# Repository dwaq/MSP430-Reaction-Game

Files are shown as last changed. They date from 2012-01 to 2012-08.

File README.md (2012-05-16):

MSP430-Reaction-Game
====================

The object of the game is to stop the cycling LEDs at a specific LED to test your reaction skills. The TI MSP430G2231 microcontroller drives 8 LEDs via 3 pins using a 74HC595 shift register. The speed that the LEDs flash is determined from the potentiometer wiper via the analog to digital converter in the MSP430. There are also 2 pushbuttons to start/restart and stop the game. Everything is powered from a 9V battery that is dropped down to 3.3V via a LD1117V33 voltage regulator. There is also a programming header to program the microcontroller in-circuit with a TI Launchpad.

Read the full details on my blog at http://tinkeringetc.blogspot.com/p/msp430-reaction-game.html

This work is licensed under a Creative Commons Attribution 3.0 Unported License.

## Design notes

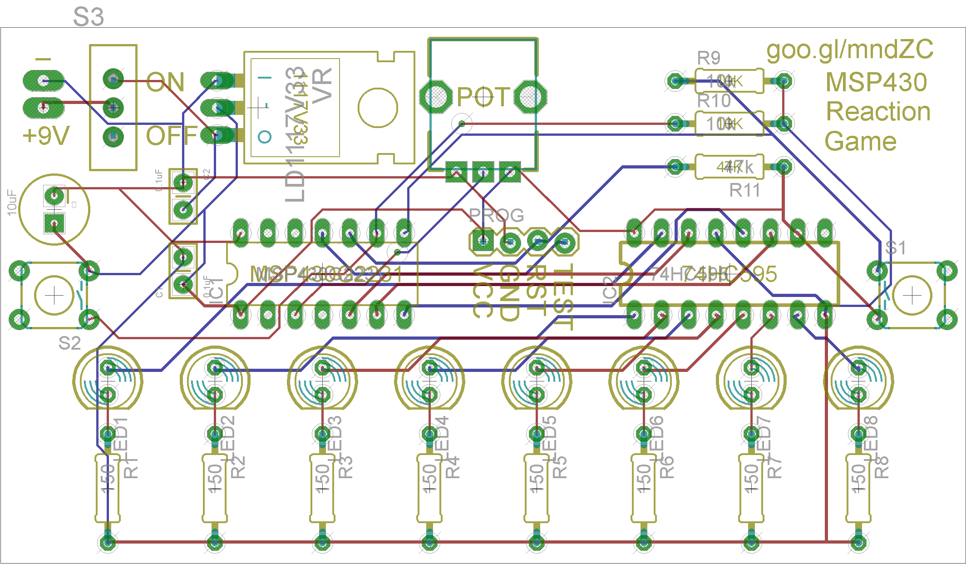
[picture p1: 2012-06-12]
ReactionGame.brd.png

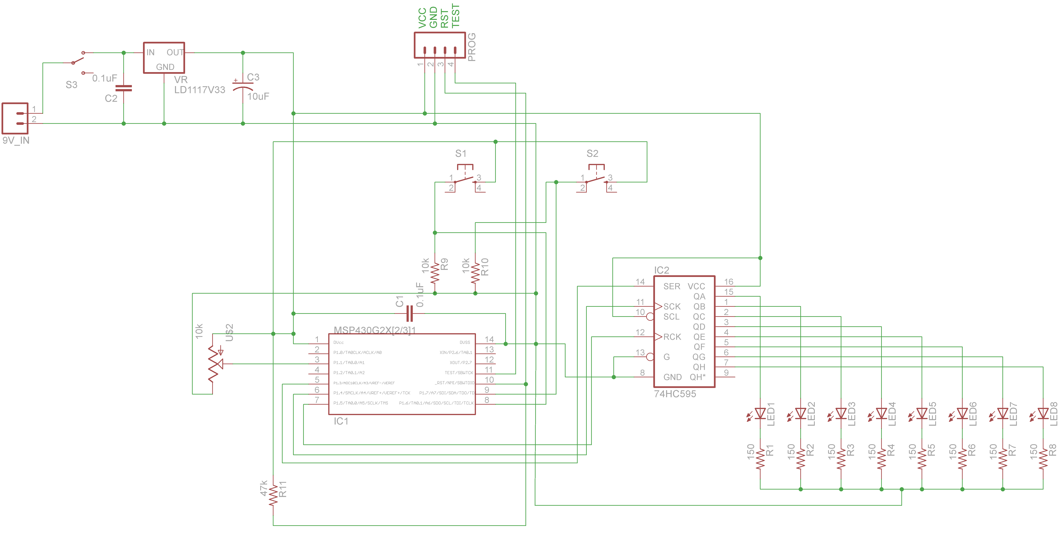
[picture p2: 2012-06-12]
ReactionGame.sch.png

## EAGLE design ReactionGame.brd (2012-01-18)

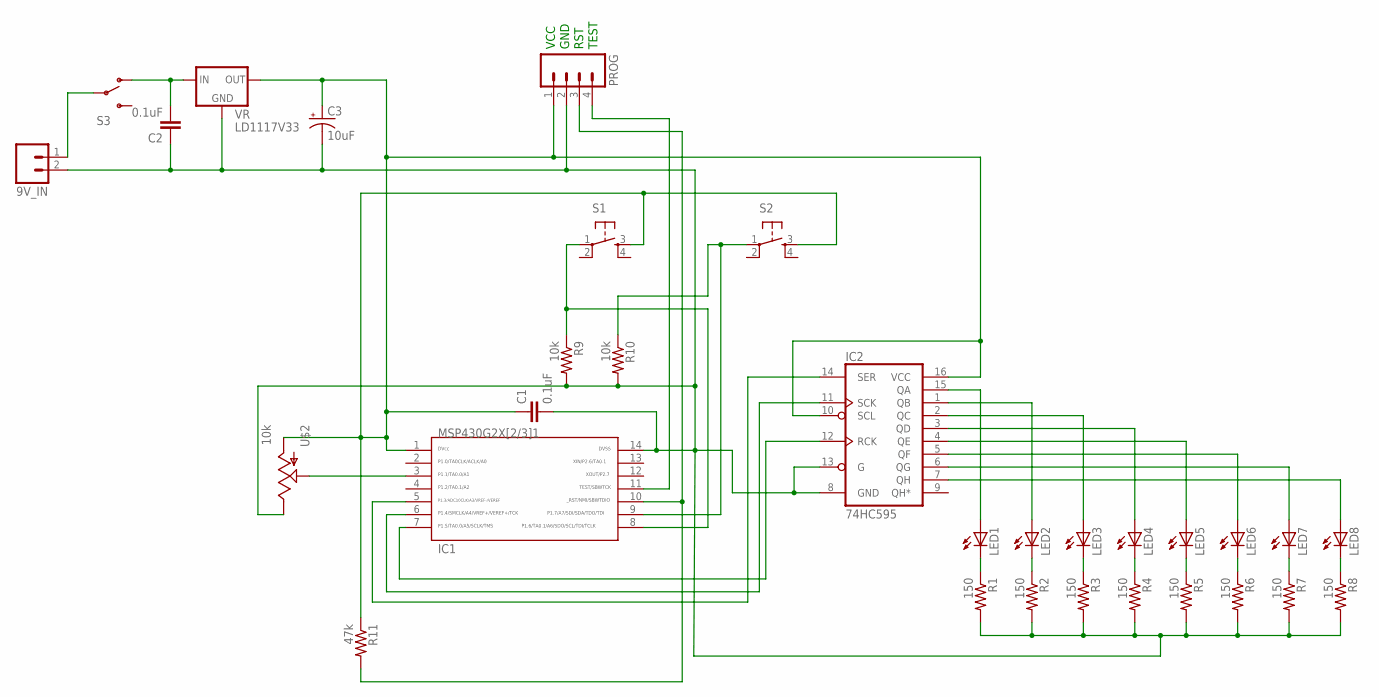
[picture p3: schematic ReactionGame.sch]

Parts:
9V_IN: M02PTH3; 1X02_LONGPADS
C1, C2: 0.1uF; CAP-PTH-SMALL2
C3: 10uF; CPOL-RADIAL-100UF-25V
IC1: MSP430G2231; N14
IC2: 74HC595; DIL16
LED1, LED2, LED3, LED4, LED5, LED6, LED7, LED8: LED5MM
PROG: M04LOCK; 1X04_LOCK
R1, R2, R3, R4, R5, R6, R7, R8: 150; 0207/10
R9, R10: 10k; 0207/10
R11: 47k; 0207/10
S1, S2: TAC_SWITCHPTH; TACTILE-PTH
S3: SWITCH-SPSTKIT; SWITCH-SPDT_KIT
U$2: 10k; ALPS_POT
VR: LD1117V33; 78XXL

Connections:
unnamed: LED1.K (C), R1.1
unnamed: LED2.K (C), R2.1
unnamed: LED3.K (C), R3.1
unnamed: LED4.K (C), R4.1
unnamed: LED5.K (C), R5.1
unnamed: LED6.K (C), R6.1
unnamed: LED7.K (C), R7.1
unnamed: LED8.K (C), R8.1
unnamed: IC2.15 (QA), LED1.A
unnamed: IC2.1 (QB), LED2.A
unnamed: IC2.2 (QC), LED3.A
unnamed: IC2.3 (QD), LED4.A
unnamed: IC2.4 (QE), LED5.A
unnamed: IC2.5 (QF), LED6.A
unnamed: IC2.6 (QG), LED7.A
unnamed: IC2.7 (QH), LED8.A
unnamed: IC1.3, U$2.P$2 (S)
unnamed: IC1.10, PROG.3, R11.2
unnamed: IC1.5, IC2.14 (SER)
unnamed: IC1.7, IC2.12 (RCK)
unnamed: IC1.6, IC2.11 (SCK)
unnamed: IC1.8, R9.1, S1.1
unnamed: IC1.9, R10.1, S2.1
unnamed: 9V_IN.2, C1.2, C2.1, C3.2 (-), IC1.14, IC2.8 (GND), IC2.13 (G), PROG.2, R1.2, R2.2, R3.2, R4.2, R5.2, R6.2, R7.2, R8.2, R9.2, R10.2, U$2.P$1 (E), VR.IN (GND)
unnamed: IC1.11, PROG.4
unnamed: 9V_IN.1, S3.2
unnamed: C2.2, S3.1 (O), VR.OUT (IN)
unnamed: C1.1, C3.1 (+), IC1.1, IC2.10 (SCL), IC2.16 (VCC), PROG.1, R11.1, S1.3, S2.3, U$2.P$3 (A), VR.GND (OUT)

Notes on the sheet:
VCC
GND
RST
TEST

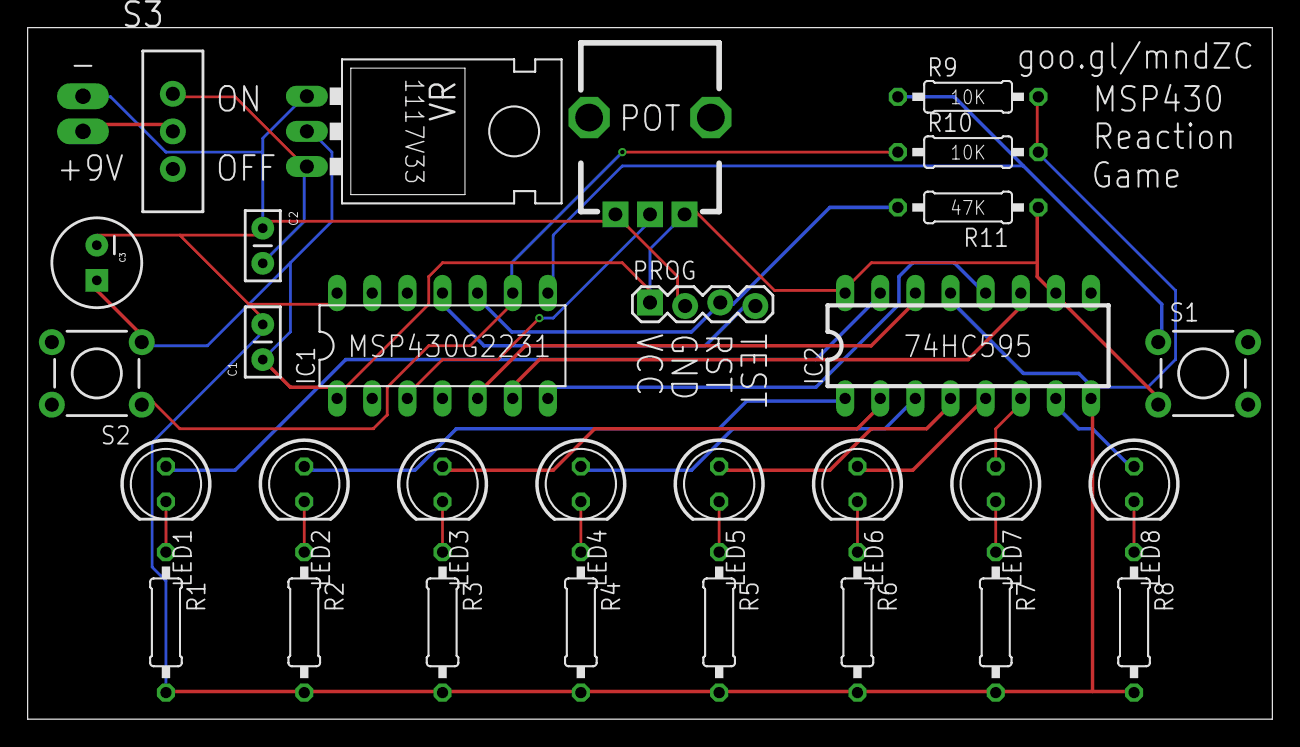
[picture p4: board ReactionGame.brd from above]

Board: 2 copper layers, 90.0 x 50.0 mm, 31 parts (0 on the bottom side), 28 nets.

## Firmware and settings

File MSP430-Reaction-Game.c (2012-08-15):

//*************************************************************************************************
// MSP430 Reaction Game
//
// By: Dillon Nichols
// http://tinkeringetc.blogspot.com/p/msp430-reaction-game.html
//
// Created in Code Composer Studio v4.2.5
//
// Description: 
// Drives 8 LEDs using a shift register at a user selected rate 
// The object of the game is to stop the LEDs at a specific LED
//
// Special thanks to:
// * TI's example code for the ADC10 located at http://www.ti.com/litv/zip/slac463a
// * Andrew Morton's example of interfacing the 74HC595 shift register to the MSP430 located at
//   http://processors.wiki.ti.com/index.php/MSP430_Launchpad_Shift_Register
// * Christopher Chenoweth's delay function located at: http://www.threadabort.com/?p=26
// * The "SCIENTIFIC INSTRUMENTS USING THE TI MSP430" blog located at http://mspsci.blogspot.com/
//
// This work is licensed under a Creative Commons Attribution 3.0 Unported License.
//*************************************************************************************************
#include "msp430g2231.h"
 
// Define pins
#define POT   BIT1 	// POTENTIOMETER -> P1.1
#define DATA  BIT3 	// PIN 14 OF 74HC595 -> P1.3
#define CLOCK BIT4 	// PIN 11 OF 74HC595 -> P1.4
#define LATCH BIT5 	// PIN 12 OF 74HC595 -> P1.5
#define STOP  BIT6 	// GAME STOP / RESTART BUTTON -> P1.6
#define START BIT7	// LED START / RESET BUTTON -> P1.7

// Declare functions
void game (void);
void stop (void);
void restart (void);
void delay (unsigned int);
void pinWrite (unsigned int, unsigned char);
void pulseClock (void);
void shiftOut (unsigned char);

// Store time between LED flashes as a global variable so all functions can access it
int delayTime;		

// Uses potentiometer through the ADC10 to select how quickly LEDs will cycle
int main(void) {
	WDTCTL = WDTPW + WDTHOLD;					// Stop WDT
	ADC10CTL0 = ADC10SHT_2 + ADC10ON + ADC10IE;	// ADC10ON, interrupt enabled
	ADC10CTL1 = INCH_1;							// input A1
	ADC10AE0 |= 0x02;							// P1.1 ADC input select
	P1DIR |= (DATA + CLOCK + LATCH);			// Setup shift register pins as outputs

  	// Reads ADC values and lights LEDS and sets the delay time corresponding to the input voltage
  	// Lower values on the ADC equals more delayTime
	for (;;) {
		ADC10CTL0 |= ENC + ADC10SC;             // Sampling and conversion start
  		__bis_SR_register(CPUOFF + GIE);        // LPM0, ADC10_ISR will force exit
		
		if (ADC10MEM > 0x000) {
  			shiftOut(1 << 7);
  			delayTime = 100;  }
	  	if (ADC10MEM > 0x07F) {
  			shiftOut(1 << 6);
  			delayTime = 90;   }
	  	if (ADC10MEM > 0x0FF) {
		  	shiftOut(1 << 5);
		  	delayTime = 80;   }
	  	if (ADC10MEM > 0x17F) {
		  	shiftOut(1 << 4);
		  	delayTime = 70;   }
	  	if (ADC10MEM > 0x1FF) {
		  	shiftOut(1 << 3);
		  	delayTime = 60;   }
	  	if (ADC10MEM > 0x27F) {
		  	shiftOut(1 << 2);
		  	delayTime = 50;   }
		if (ADC10MEM > 0x2FF) {
		  	shiftOut(1 << 1);
		  	delayTime = 40;   }
		if (ADC10MEM > 0x37F) {
	    	shiftOut(1 << 0);
	    	delayTime = 30;   }
	  	if ((P1IN & START) == START) {	// When the START button is pressed, the game
	  		game();         }			// will start with the selected delayTime	
	}
}

// ADC10 interrupt service routine
#pragma vector=ADC10_VECTOR
__interrupt void ADC10_ISR(void)
{
  __bic_SR_register_on_exit(CPUOFF);	// Clear CPUOFF bit from 0(SR)
}

// Function that flashes the LEDs back and forth with a delay between LEDs of delayTime
// Waits for the STOP button to be pressed to stop the LED and win/(lose?) the game
void game(void){
	for (;;){
    	shiftOut(1 << 0);
      	delay(delayTime); 
      	if ((P1IN & STOP) == STOP) {stop();}
    	shiftOut(1 << 1);
      	delay(delayTime); 
      	if ((P1IN & STOP) == STOP) {stop();}
      	shiftOut(1 << 2);
      	delay(delayTime); 
      	if ((P1IN & STOP) == STOP) {stop();}
      	shiftOut(1 << 3);
      	delay(delayTime); 
      	if ((P1IN & STOP) == STOP) {stop();}
      	shiftOut(1 << 4);
      	delay(delayTime); 
      	if ((P1IN & STOP) == STOP) {stop();}
      	shiftOut(1 << 5);
      	delay(delayTime); 
      	if ((P1IN & STOP) == STOP) {stop();}
      	shiftOut(1 << 6);
      	delay(delayTime); 
      	if ((P1IN & STOP) == STOP) {stop();}
      	shiftOut(1 << 7);
      	delay(delayTime); 
      	if ((P1IN & STOP) == STOP) {stop();}
      	shiftOut(1 << 6);
      	delay(delayTime); 
      	if ((P1IN & STOP) == STOP) {stop();}
      	shiftOut(1 << 5);
      	delay(delayTime); 
      	if ((P1IN & STOP) == STOP) {stop();}
      	shiftOut(1 << 4);
      	delay(delayTime); 
      	if ((P1IN & STOP) == STOP) {stop();}
      	shiftOut(1 << 3);
      	delay(delayTime); 
      	if ((P1IN & STOP) == STOP) {stop();}
      	shiftOut(1 << 2);
      	delay(delayTime); 
      	if ((P1IN & STOP) == STOP) {stop();}
      	shiftOut(1 << 1);
      	delay(delayTime); 
      	if ((P1IN & STOP) == STOP) {stop();}
	}
}

// Ensures that the STOP button is released after finishing a game
void stop (void) {
	for (;;) {
		if ((P1IN & STOP) == STOP) {			// Waits to STOP button to be pressed
			delay(50);
  			if ((P1IN & STOP) != STOP) {		// Waits for STOP buton to be released so it 
  				restart();				
  			}
		}
	}
}

// Gives the user the option to restart at the same speed with the STOP button
// or select a new speed with the START button
void restart (void) {
	for (;;) {
		if ((P1IN & START) == START) {			// Waits to START button to be pressed
			delay(50);
	  		if ((P1IN & START) != START) {		// Waits for START buton to be released so it 
	  			main();							// does not interfere with the main function
	  		}
		}
		if ((P1IN & STOP) == STOP) {			// Waits to STOP button to be pressed
			delay(50);
	  		if ((P1IN & STOP) != STOP) {		// Waits for STOP buton to be released so it 
	  			game();							// does not interfere with the game function
	  		}
		}
	}
}


// Delays by the specified Milliseconds
void delay(unsigned int ms) {
 	while (ms--) {
		__delay_cycles(1000);
    }
}
 
// Writes a value to the specified bitmask/pin. Use built in defines
// when calling this, as the shiftOut() function does.
// All nonzero values are treated as "high" and zero is "low"
void pinWrite(unsigned int bit, unsigned char val) {
  	if (val){
    	P1OUT |= bit;
  	} else {
    	P1OUT &= ~bit;
  	}
}
 
// Pulse the clock pin
void pulseClock(void){
  	P1OUT |= CLOCK;
  	P1OUT ^= CLOCK;
}
 
// Take the given 8-bit value and shift it out, LSB to MSB
void shiftOut(unsigned char val){
  	//Set latch to low (should be already)
  	P1OUT &= ~LATCH;
 
  	char i;
 
  	// Iterate over each bit, set data pin, and pulse the clock to send it to the shift register
  	for (i = 0; i < 8; i++)  {
      	pinWrite(DATA, (val & (1 << i)));
      	pulseClock();
  	}
 
  	// Pulse the latch pin to write the values into the storage register
  	P1OUT |= LATCH;
  	P1OUT &= ~LATCH;
}

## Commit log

2012-01-18 removed some files to rename later on
    [MSP430-Reaction-Game.brd, MSP430-Reaction-Game.sch]
2012-01-18 Eagle files sent to manufacture
    [ReactionGame.brd, ReactionGame.sch]
2012-02-08 Gerber board files sent for manufacture
    [ReactionGame.GBL, ReactionGame.GBO, ReactionGame.GBS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]
2012-02-08 Switched buttons around in code to match what is on the PCB

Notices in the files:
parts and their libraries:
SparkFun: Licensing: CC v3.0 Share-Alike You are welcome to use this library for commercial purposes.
